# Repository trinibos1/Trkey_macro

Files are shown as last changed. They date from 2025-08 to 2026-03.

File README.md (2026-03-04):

# Trkey Macropad
## Overview

This is a **compact 3×3 macropad** built with **Raspberry Pi Pico / RP2040**, running **CircuitPython/Arduino**. It connects via **USB** using the **Adafruit HID library**, allowing you to assign keyboard shortcuts, media keys, and macros. An **OLED display** shows layer and status information for easy feedback. 
* **OLED Display:** [Amazon Link](https://a.co/d/afDOQYH)
* **PCB Design:** [OSH Park Project](https://oshpark.com/shared_projects/1jOtq57X)
* **Web Key Mapper:** [trinibos1/Trkey\_mapper](https://trinibos1.github.io/TRkey_mapper/)

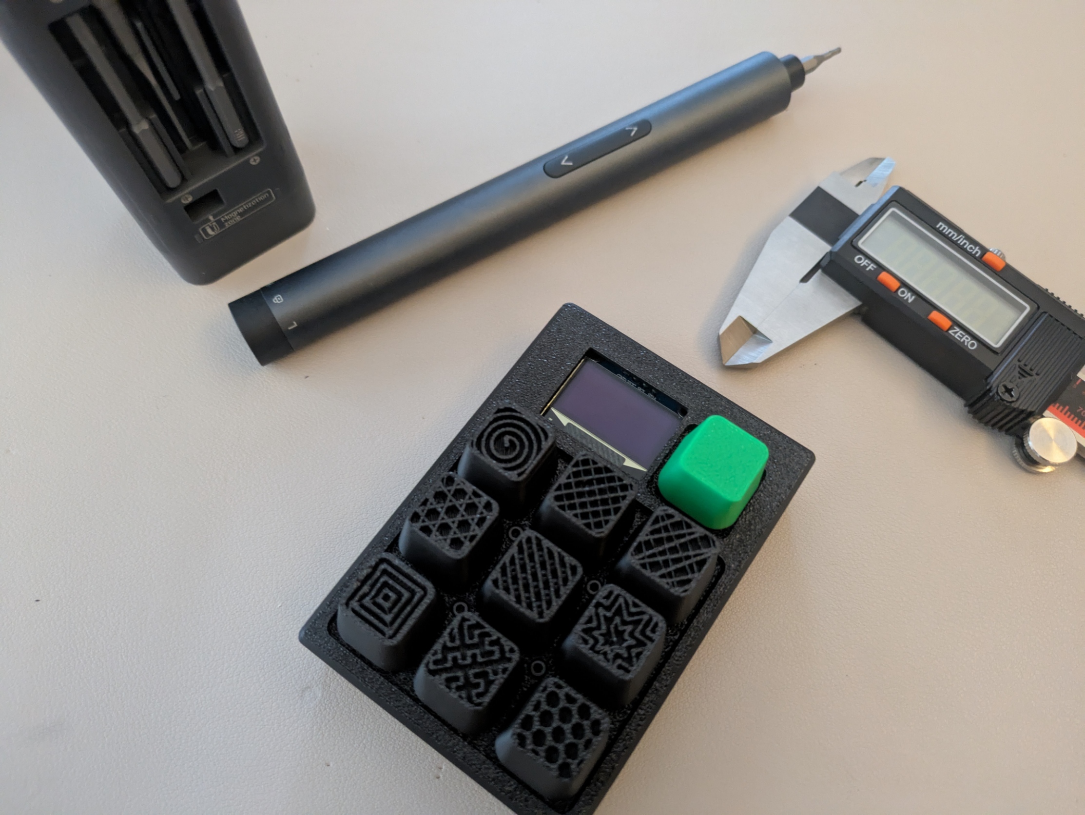
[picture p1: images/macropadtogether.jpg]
PCB Image

---
## Update

* UF2 file is old but code is up to date
* wireless trkey macropad has started development
---
## Changelog / Update Log

- **2026-02-14**
  - Added startup boot animation to main Arduino sketch (`arduino/Trkey_macro.ino`) with 3x3 box reveal, `TRKEY` splash, and version text.
  - Added dedicated WebSerial + USB connection guide (`WEBSERIAL_CONNECTION.md`).
  - Improved Arduino firmware compatibility and robustness:
    - HID report ID fixes for keyboard/media reports.
    - Numeric key token support (`"1".."0"`) plus legacy aliases (`"ONE".."ZERO"`).
    - RAM-backed `layers.json` handling when LittleFS is unavailable.
    - Safer JSON fallback behavior and macro ID parsing improvements.
    - USB descriptor naming updates for Trkey product/manufacturer.

## Features

* 3×3 Cherry MX Brown Hyperglide 45g tactile mechanical key matrix
* USB HID support (no Bluetooth)
* OLED display for layer/status feedback
* Tap/Hold functionality for advanced key actions
* Multiple layers for extended shortcut options
* Fast and responsive keypresses
* Simple wiring: switches connect directly to GND
* **All-in-one UF2:** CircuitPython, libraries, and firmware code included

---

## Hardware

| Component | Details |
| --- | --- |
| Microcontroller | Raspberry Pi Pico / RP2040 |
| Switches | 9x Cherry MX Brown Hyperglide 45g tactile |
| Display | OLED I2C 128x32 ([link](https://a.co/d/afDOQYH)) |
| PCB | Custom 3×3 macropad ([link](https://oshpark.com/shared_projects/1jOtq57X)) |
| Power | USB only |

PCB 
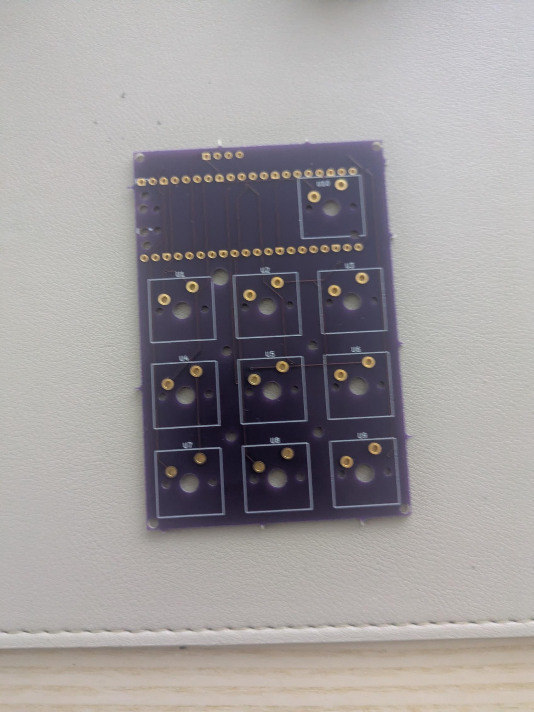
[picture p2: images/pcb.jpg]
PCB Image


---

## Firmware

**UF2 Firmware:**


* `macropad.uf2` — stable, all-in-one with CircuitPython, libraries, and code
* `dev_firmware.uf2` — development version for testing new features

**Key Features:** Tap/Hold, Layers, Media keys

### Arduino IDE firmware (C/C++)

If you want to move from CircuitPython to Arduino IDE, use `arduino/Trkey_macro.ino`.

Startup animation is now included in the main sketch (`arduino/Trkey_macro.ino`).

For beta experiments, you can still use `arduino/Trkey_macro_Beta.ino` (also provided as `arduino/Trkey_macro Beta.ino`).

This sketch keeps the same behavior as `code.py`:
- 3x3 key scanning with debounce + key repeat
- Layer functions: `MO(x)`, `TO(x)`, `TT(x)`, `DF(x)`
- Media keys + keyboard combos + text macros (`MACRO_n`)
- Text macro typing fallback is ASCII-only (`A-Z`, `a-z`, `0-9`, space, newline)
- OLED layer/key UI (with highlighted key and boxed grid)
- Serial command protocol for `LIST`, `GET`, `PUT`, `DEL`, `RELOAD`
- Macros can be defined on any layer; duplicate IDs use the last parsed definition

Required Arduino libraries:
- Adafruit SSD1306
- Adafruit GFX Library
- TinyUSB from the RP2040 board core (`Adafruit_TinyUSB_Arduino`)
- ArduinoJson
- LittleFS (included with RP2040 core)

Recommended board core: **Raspberry Pi Pico/RP2040** (Earle Philhower core).

RP2040 TinyUSB note (important):
- Do **not** call `tusb_init()` in your sketch (the RP2040 Arduino core already initializes TinyUSB).
- Prefer the TinyUSB bundled with the RP2040 core (`Adafruit_TinyUSB_Arduino`).
- If you installed `Documents/Arduino/libraries/Adafruit_TinyUSB_Library`, remove it to avoid library conflicts.

Documentation:
- `WEBSERIAL_CONNECTION.md` — USB CDC/WebSerial command flow, upload handshake, persistence behavior, and troubleshooting.
- `layers.json` in repo root — example keymap/profile format used by firmware and mapper.

---

## Usage

1. **Flash the UF2** (`macropad.uf2` or `dev_firmware.uf2`) onto your Pico — everything is included, no additional setup needed.
2. **Plug in the macropad** — ready to use.
3. **Use your macropad**:

   * Tap switches for primary actions
   * Hold switches for secondary actions or layer switching
   * OLED displays the current layer and status

---

## Companion App (Beta)

This beta feature is implemented in **Arduino firmware** (`arduino/Trkey_macro.ino`) and an optional PC CLI app (`pc_companion/trkey_music_companion.py`).

- The macropad still works fully without the companion app.
- Companion mode adds now-playing OLED metadata and app events.
- You can switch to music layer by name with: `MODE music`.

Quick start:
1. Flash Arduino beta firmware (`arduino/Trkey_macro_Beta.ino`).
1. Flash Arduino firmware (`arduino/Trkey_macro.ino`).
2. Run companion app: `python pc_companion/trkey_music_companion.py --port <PORT>`.
3. In app CLI, type:
   - `music` to load the music layer by name.
   - `np Song|Artist|45|180|Spotify` to update metadata.

Supported companion key tokens (in `layers.json`):
- `APP_PLAY_PAUSE`
- `APP_NEXT`
- `APP_PREV`
- `APP_MUTE`
- `APP_VOL_UP`
- `APP_VOL_DOWN`
- `APP_SEEK_FWD_10`
- `APP_SEEK_BACK_10`

`APP_*` keys emit `APP_EVENT <token>` on serial and media actions also fallback to HID media controls.

## Web-Based Key Mapper

Customize your macropad's key bindings using the **web-based key mapper**:

* Full key remapping: Assign single keys or complex shortcuts to any of the 9 keys
* Multi-layer support: Configure multiple layers for extended functionality
* Macro support: Create macros for complex sequences
* Web Serial API: Communicate directly with your macropad via the browser

**Access the key mapper here:** [trinibos1/micropad\_web](https://github.com/trinibos1/micropad_web)

---

## Contributions

Contributions are welcome to **improve the key library**, including:

* Adding new key mappings or shortcuts
* Optimizing tap/hold behavior
* Enhancing multi-layer support
* Improving key response and stability

Submit issues or pull requests to collaborate.
---
## 🙌 Thanks

Huge thanks to **[Adafruit](https://www.adafruit.com/)** for their amazing hardware and the **CircuitPython** + library ecosystem.  
Without their work, projects like this macropad wouldn’t be possible. 💜
---

## License

MIT License – see [LICENSE](LICENSE) for details.
---
## contact
Email: Trinibos1@proton.me

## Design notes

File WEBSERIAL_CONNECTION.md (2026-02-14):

# Trkey WebSerial + USB Connection Guide

This document explains how Trkey firmware communicates with the web app over USB Serial, how uploads are acknowledged, and how USB naming works.

## 1) USB Modes Used by Firmware

The firmware exposes:

- **USB HID** (keyboard + consumer/media reports)
- **USB CDC Serial** (line-based command channel used by Trkey Mapper)

At startup, firmware sets USB descriptor strings to:

- Manufacturer: `Trkey`
- Product: `Trkey`
- Serial: `TRKEY`

> Note: some OS UIs still show a generic serial path (`COMx`, `/dev/ttyACM*`, `/dev/cu.usbmodem*`) even when product/manufacturer strings are set correctly.

## 2) WebSerial Command Protocol

All commands are newline-terminated text lines.

### `LIST`

**Send:**

`LIST`

**Reply:**

- `Files:`
- one filename per line
- `<END>`

If LittleFS is unavailable, firmware still reports:
# Trkey WebSerial Connection Guide

This document explains how the Trkey firmware connects to the web app (Trkey Mapper) over USB Serial and which command flow is expected.

## Overview

The Arduino firmware exposes a simple line-based protocol on USB CDC Serial (`Serial`) so the browser app can:

- list files
- read `layers.json`
- upload `layers.json`
- reload layers in runtime

The command handler is in `arduino/Trkey_macro.ino` (`handleCommand()` + `processSerial()`).

## Serial Protocol

All commands are newline-terminated text lines.

### 1) LIST

**App sends**

`LIST`

**Firmware replies**

- `Files:`
- one file per line
- `<END>`

If LittleFS is unavailable, firmware still returns:

- `layers.json`
- `<END>`

### `GET <file>`

**Send:**

`GET layers.json`

**Reply:**

- raw file bytes
- `<EOF>` marker (`<EOF>\n`)

When filesystem is unavailable:

- returns RAM-backed `layers.json` (if uploaded in this runtime), otherwise
- returns built-in default JSON.

### `PUT <file>`

**Send:**

`PUT layers.json`

**Immediate reply:**

`READY`

Then app sends file bytes and terminates stream with:

`<EOF>`

**Completion replies:**

- `FILE RECEIVED`
- for `layers.json`: `LAYERS RELOADED`

### `RELOAD`

**Send:**

`RELOAD`

**Reply:**

`LAYERS RELOADED`

### `DEL <file>`

Deletes a file from LittleFS. If FS is unavailable, returns `ERROR`.

## 3) Expected Upload Handshake

Recommended app flow:

1. Send `PUT layers.json`
2. Wait for `READY`
### 2) GET <file>

**App sends**

`GET layers.json`

**Firmware replies**

- raw file bytes
- `<EOF>` marker (sent as `<EOF>\n`)

If filesystem is unavailable:

- returns RAM-backed `layers.json` if one was uploaded in this session
- otherwise returns firmware default JSON

### 3) PUT <file>

**App sends**

`PUT layers.json`

**Firmware replies first**

`READY`

Then app streams file contents and terminates with:

`<EOF>`

**Firmware replies after EOF**

- `FILE RECEIVED`
- for `layers.json`, it then reloads and sends `LAYERS RELOADED`

### 4) RELOAD

**App sends**

`RELOAD`

**Firmware replies**

`LAYERS RELOADED`

## Why you may see "READY" + "FILE RECEIVED"

This is expected behavior for `PUT`:

1. firmware acknowledges upload start with `READY`
2. app sends bytes + `<EOF>`
3. firmware confirms write with `FILE RECEIVED`
4. firmware reloads config and emits `LAYERS RELOADED`

If the web app is currently waiting only for `FILE RECEIVED`, a delayed `READY` line can appear as an "unexpected line" in logs even though the flow is healthy.

## Persistence Behavior

- If LittleFS is available: uploaded `layers.json` is written to flash.
- If LittleFS is unavailable: uploaded `layers.json` is stored in RAM (`ramLayersJson`) for this runtime session.

That RAM-backed path allows `GET layers.json` and `RELOAD` to keep using the uploaded config even without filesystem access.

## Minimal App Upload Sequence (recommended)

1. Send `PUT layers.json`
2. Wait until `READY`
3. Send JSON bytes
4. Send `<EOF>`
5. Wait for `FILE RECEIVED`
6. Optionally wait for `LAYERS RELOADED`

If `READY` appears as an "unexpected line" while waiting for `FILE RECEIVED`, that usually means your app state machine consumed lines out of phase. The firmware sequence above is expected.

## 4) Persistence Behavior

- **LittleFS available:** upload is persisted to flash.
- **LittleFS unavailable:** upload is stored in RAM for this runtime session.

RAM-backed config supports `GET layers.json` + `RELOAD`, but it is not power-cycle persistent.

## 5) JSON Compatibility Notes

Firmware accepts both:

- top-level array of layers, or
- object with a `layers` array (recommended)

It supports numeric key tokens (`"1".."0"`) and word aliases (`"ONE".."ZERO"`).

## 6) Troubleshooting

- `UNKNOWN COMMAND`: command is malformed or not newline-terminated.
- `FILE RECEIVED` never arrives: app did not send `<EOF>` marker correctly.
- Config reloads but seems unchanged: verify uploaded JSON parses and layer keys are valid tokens.
- Device name not updated: reflash and unplug/replug to force USB re-enumeration.
## Troubleshooting

- If the device returns `UNKNOWN COMMAND`, verify each command is newline-terminated.
- If upload appears successful but config is unchanged, ensure app waits for `READY` before sending file bytes.
- If filesystem is unavailable, behavior is session-persistent only (RAM), not power-cycle persistent.

### 5) NP_SET <json>

Send now-playing metadata from the optional PC companion app.

**Send**

`NP_SET {"title":"Track","artist":"Artist","position":12,"duration":180,"source":"Spotify"}`

**Reply**

`NP_OK`

Notes:
- Metadata is in RAM only.
- OLED switches to a now-playing overlay and auto-hides after inactivity.

### 6) NP_CLEAR

**Send**

`NP_CLEAR`

**Reply**

`NP_CLEARED`

### 7) NP_GET

**Send**

`NP_GET`

**Reply**

single-line JSON of current now-playing state.

### Companion action events

When a key is mapped to an `APP_*` token in `layers.json`, firmware emits:

`APP_EVENT <token>`

Example:

`APP_EVENT APP_PLAY_PAUSE`

These actions are optional companion features. The macropad does not require a companion app for normal HID operation.

### 8) MODE <name-or-index>

Switch active layer by index or name.

**Examples**
- `MODE 3`
- `MODE music`

Name matching is case-insensitive and supports partial match.

**Reply**
- `MODE LOADED`
- or `ERROR: MODE NOT FOUND`

### 9) MODE LIST

List available layer names for mode switching.

**Send**

`MODE LIST`

**Reply**
- `Modes:`
- `<index>: <layer-name>` per line
- `<END>`

### PC app

A basic optional PC companion CLI app is included at:

`pc_companion/trkey_music_companion.py`

It supports `music` shortcut (`MODE music`), metadata pushes (`NP_SET`), and prints `APP_EVENT` lines.

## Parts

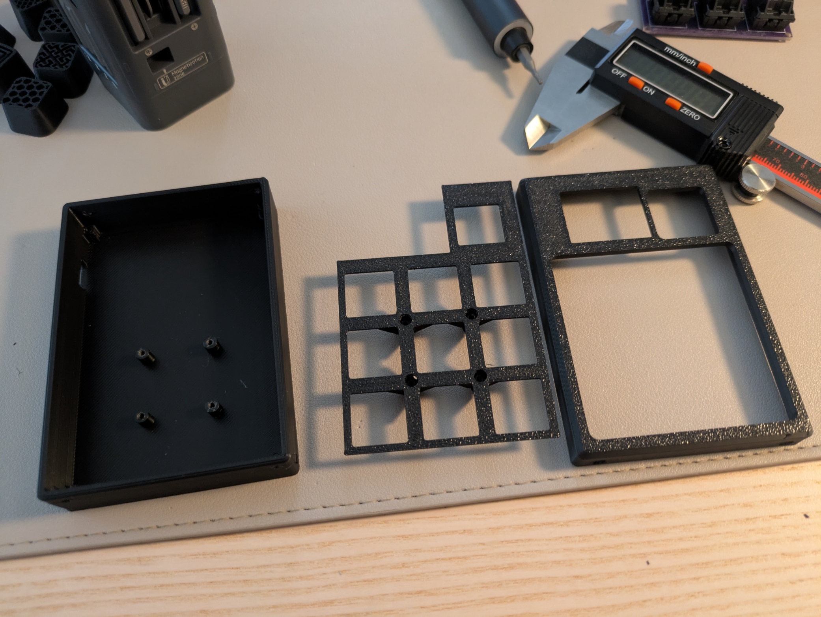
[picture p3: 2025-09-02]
images/macropad printed parts nly.jpg

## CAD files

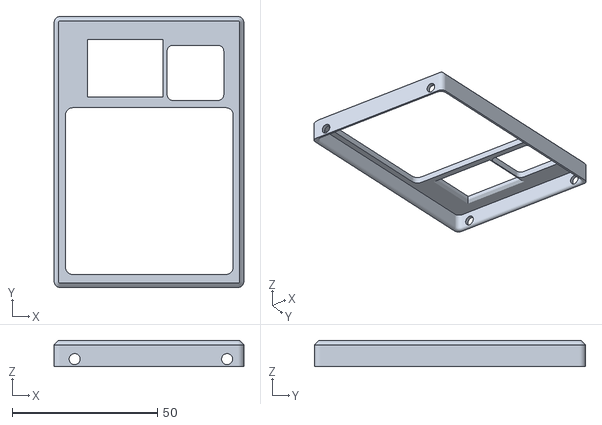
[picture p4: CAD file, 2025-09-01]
case/oldcase/macropad top.stl
65.3 x 93.3 x 9.00

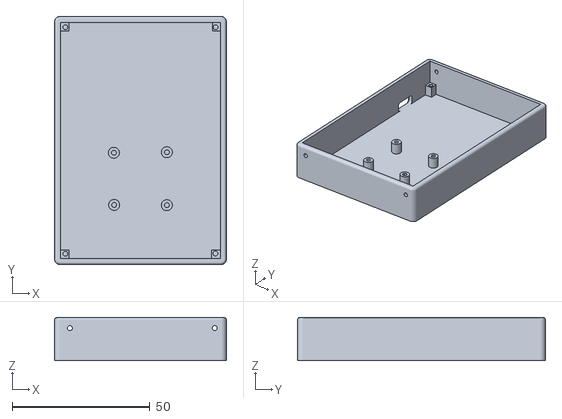
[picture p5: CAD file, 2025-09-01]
case/oldcase/macropad bottom .stl
62.3 x 89.9 x 15.7

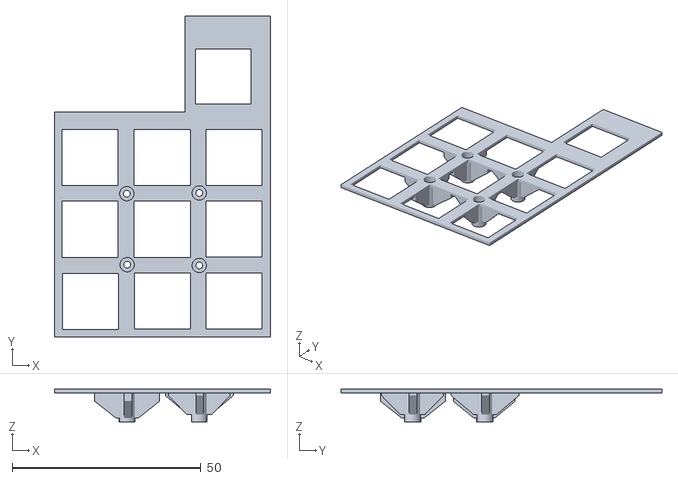
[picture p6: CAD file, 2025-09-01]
case/oldcase/macropad mid.stl
57.2 x 85.0 x 8.62

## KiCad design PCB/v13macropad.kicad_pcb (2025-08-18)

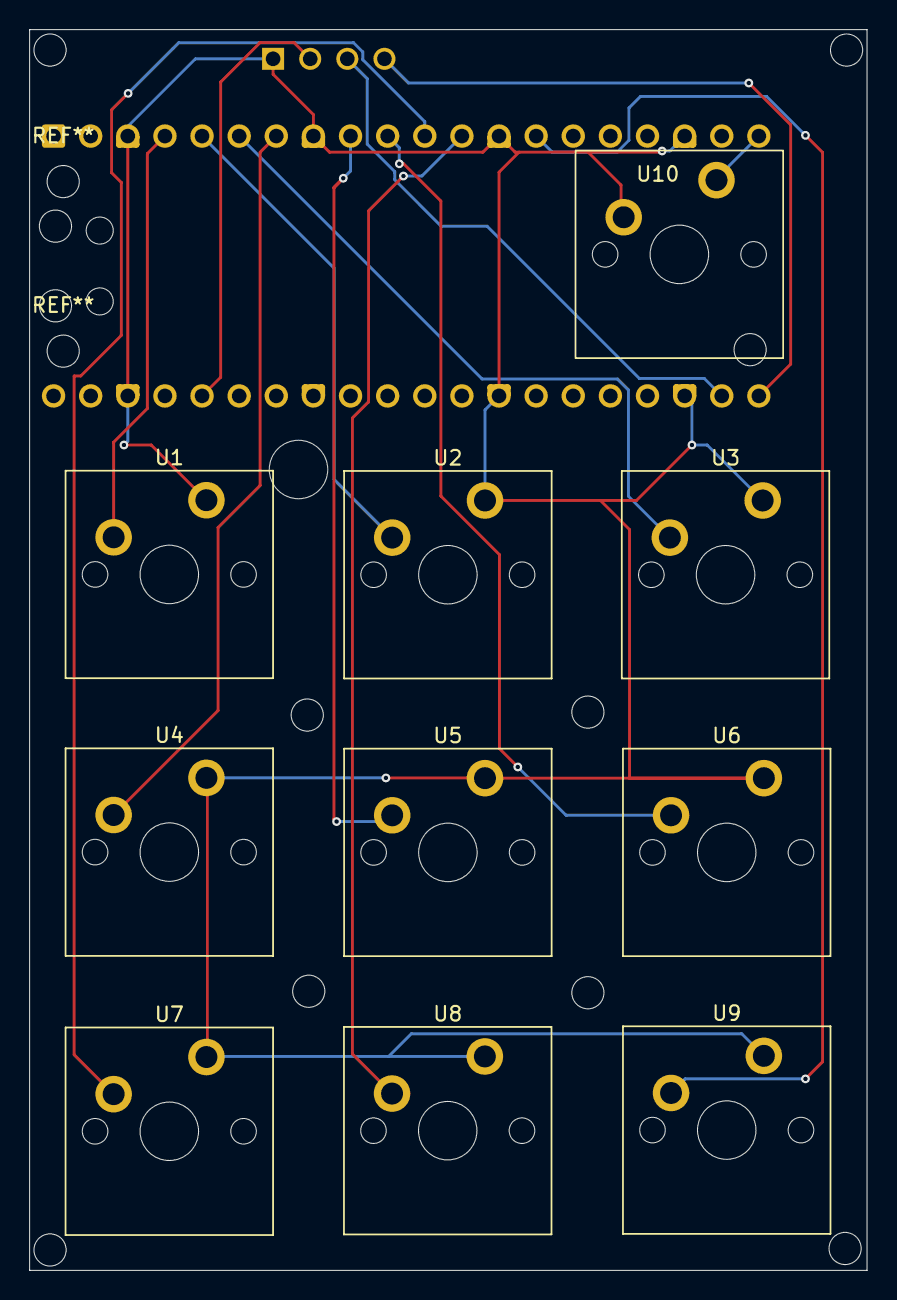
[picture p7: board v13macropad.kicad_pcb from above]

Board: 2 copper layers, 57.3 x 84.9 mm, 12 parts (1 on the bottom side), 11 nets.

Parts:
A1: RaspberryPi_Pico; RaspberryPi_Pico_Common
U1, U2, U3, U4, U5, U6, U7, U8, U9, U10: MX1A-11NN; SW_Cherry_MX_PCB_1.00u
U11: DM-OLED096-636; MODULE_DM-OLED096-636

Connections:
BAT+: A1.6 (GPIO4), A1.10 (GPIO7), A1.14 (GPIO10), A1.36 (3V3), A1.39 (VSYS), A1.40 (VBUS), U3.1, U6.1, U9.1, U11.2 (VCC_IN)
Earth: A1.3 (GND), A1.8 (GND), A1.13 (GND), A1.18 (GND), A1.23 (GND), A1.28 (GND), A1.38 (GND), U1.2, U2.2, U3.2, U4.2, U5.2, U6.2, U7.2, U8.2, U9.2, U10.1, U11.1 (GND)
unnamed: A1.4 (GPIO2), U1.1
unnamed: A1.5 (GPIO3), U2.1
unnamed: A1.7 (GPIO5), U4.1
unnamed: A1.9 (GPIO6), U5.1
unnamed: A1.11 (GPIO8), U7.1
unnamed: A1.12 (GPIO9), U8.1
unnamed: A1.20 (GPIO15), U10.2
unnamed: A1.21 (GPIO16), U11.4 (SDA)
unnamed: A1.22 (GPIO17), U11.3 (SCL)

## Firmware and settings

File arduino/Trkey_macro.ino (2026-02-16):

#include <Arduino.h>
#include <Wire.h>
#include <Adafruit_GFX.h>
#include <Adafruit_SSD1306.h>
#include <Adafruit_TinyUSB.h>
#include <ArduinoJson.h>
#include <EEPROM.h>
#include <map>
#include <vector>

// ===== Firmware Version =====
#define FW_VERSION "v2.5.4"

// ===== Display =====
static constexpr uint8_t OLED_ADDR = 0x3C;
static constexpr int SCREEN_WIDTH = 128;
static constexpr int SCREEN_HEIGHT = 64;
Adafruit_SSD1306 display(SCREEN_WIDTH, SCREEN_HEIGHT, &Wire, -1);

// ===== Timing =====
static constexpr uint32_t DEBOUNCE_MS = 100;
static constexpr uint32_t PRESS_DISPLAY_MS = 300;
static constexpr uint32_t REPEAT_DELAY_MS = 400;
static constexpr uint32_t REPEAT_RATE_MS = 50;

// ===== Pins =====
const uint8_t keyPins[9] = {2, 3, 4, 5, 6, 7, 8, 9, 10};
const uint8_t layerSwitchPin = 15;

// ===== TinyUSB HID (WORKING from your code) =====
Adafruit_USBD_HID usb_hid;
uint8_t const hidReportDescriptor[] = {
  TUD_HID_REPORT_DESC_KEYBOARD(HID_REPORT_ID(1)),
  TUD_HID_REPORT_DESC_CONSUMER(HID_REPORT_ID(2))
};
static constexpr uint8_t KEYBOARD_REPORT_ID = 1;
static constexpr uint8_t CONSUMER_REPORT_ID = 2;

// ===== EEPROM Config Storage =====
#define EEPROM_SIZE 16384
#define CONFIG_ADDR 0
#define CONFIG_MAGIC 0xDEADBEEF

// ===== Config models =====
struct Layer {
  String name;
  String labels[9];
  String keys[9];
};

std::vector<Layer> layers;
std::map<int, String> macros;
int currentLayer = 0;
int defaultLayer = 0;

// ===== Key state =====
bool repeatActive[9] = {false};
uint32_t repeatStart[9] = {0};
uint32_t repeatLast[9] = {0};
uint32_t keyDebounceStart[9] = {0};
bool moActive[9] = {false};
int moPrevLayer[9] = {0};
int moTargetForKey[9] = {0};
int pressedIndex = -1;
uint32_t lastPressMs = 0;
bool lastLayerSwitchState = true;

// ===== CDC transfer state =====
bool receivingFile = false;
String putFilename;
String serialLineBuffer;
uint8_t eofWindow[5] = {0};
uint8_t eofWindowLen = 0;
bool discardingUpload = false;
String putBuffer;

// ===== HID maps =====
std::map<String, uint8_t> keyMap;
std::map<String, uint16_t> consumerMap;

String normalizePathArg(const String& rawArg) {
  String f = rawArg;
  f.trim();
  while (f.startsWith("/")) f.remove(0, 1);
  return f.length() ? String("/") + f : String("/");
}

const char* defaultLayersJson() {
  return R"JSON({"grid_size":3,"layers":[{"name":"Layer 0","labels":["A","B","C","D","E","F","G","H","I"],"keys":["A","B","C","D","E","F","G","H","I"]}]})JSON";
}

void sendLine(const char* msg) {
  Serial.print(msg);
  Serial.print("\n");
  Serial.flush();
}

void sendEOFMarker() {
  Serial.write(reinterpret_cast<const uint8_t*>("<EOF>\n"), 6);
  Serial.flush();
}

void initKeyMaps() {
  keyMap["A"] = HID_KEY_A; keyMap["B"] = HID_KEY_B; keyMap["C"] = HID_KEY_C;
  keyMap["D"] = HID_KEY_D; keyMap["E"] = HID_KEY_E; keyMap["F"] = HID_KEY_F;
  keyMap["G"] = HID_KEY_G; keyMap["H"] = HID_KEY_H; keyMap["I"] = HID_KEY_I;
  keyMap["J"] = HID_KEY_J; keyMap["K"] = HID_KEY_K; keyMap["L"] = HID_KEY_L;
  keyMap["M"] = HID_KEY_M; keyMap["N"] = HID_KEY_N; keyMap["O"] = HID_KEY_O;
  keyMap["P"] = HID_KEY_P; keyMap["Q"] = HID_KEY_Q; keyMap["R"] = HID_KEY_R;
  keyMap["S"] = HID_KEY_S; keyMap["T"] = HID_KEY_T; keyMap["U"] = HID_KEY_U;
  keyMap["V"] = HID_KEY_V; keyMap["W"] = HID_KEY_W; keyMap["X"] = HID_KEY_X;
  keyMap["Y"] = HID_KEY_Y; keyMap["Z"] = HID_KEY_Z;
  keyMap["1"] = HID_KEY_1; keyMap["2"] = HID_KEY_2; keyMap["3"] = HID_KEY_3;
  keyMap["4"] = HID_KEY_4; keyMap["5"] = HID_KEY_5; keyMap["6"] = HID_KEY_6;
  keyMap["7"] = HID_KEY_7; keyMap["8"] = HID_KEY_8; keyMap["9"] = HID_KEY_9;
  keyMap["0"] = HID_KEY_0;
  keyMap["ENTER"] = HID_KEY_ENTER;
  keyMap["ESCAPE"] = HID_KEY_ESCAPE;
  keyMap["TAB"] = HID_KEY_TAB;
  keyMap["SPACE"] = HID_KEY_SPACE;
  keyMap["BACKSPACE"] = HID_KEY_BACKSPACE;
  keyMap["CONTROL"] = HID_KEY_CONTROL_LEFT;
  keyMap["CTRL"] = HID_KEY_CONTROL_LEFT;
  keyMap["SHIFT"] = HID_KEY_SHIFT_LEFT;
  keyMap["ALT"] = HID_KEY_ALT_LEFT;
  keyMap["GUI"] = HID_KEY_GUI_LEFT;

  consumerMap["PLAY_PAUSE"] = HID_USAGE_CONSUMER_PLAY_PAUSE;
  consumerMap["MUTE"] = HID_USAGE_CONSUMER_MUTE;
  consumerMap["VOLUME_INCREMENT"] = HID_USAGE_CONSUMER_VOLUME_INCREMENT;
  consumerMap["VOLUME_DECREMENT"] = HID_USAGE_CONSUMER_VOLUME_DECREMENT;
#if defined(HID_USAGE_CONSUMER_SCAN_NEXT)
  consumerMap["SCAN_NEXT_TRACK"] = HID_USAGE_CONSUMER_SCAN_NEXT;
#elif defined(HID_USAGE_CONSUMER_SCAN_NEXT_TRACK)
  consumerMap["SCAN_NEXT_TRACK"] = HID_USAGE_CONSUMER_SCAN_NEXT_TRACK;
#endif
#if defined(HID_USAGE_CONSUMER_SCAN_PREVIOUS)
  consumerMap["SCAN_PREVIOUS_TRACK"] = HID_USAGE_CONSUMER_SCAN_PREVIOUS;
#elif defined(HID_USAGE_CONSUMER_SCAN_PREVIOUS_TRACK)
  consumerMap["SCAN_PREVIOUS_TRACK"] = HID_USAGE_CONSUMER_SCAN_PREVIOUS_TRACK;
#endif
  consumerMap["STOP"] = HID_USAGE_CONSUMER_STOP;
}

bool isNoop(const String& s) {
  return s.length() == 0 || s == "NO_OP";
}

void drawUI(int layerIdx, int activeIdx = -1) {
  if (layers.empty()) return;
  display.clearDisplay();
  display.setTextColor(SSD1306_WHITE);
  display.setTextSize(1);
  display.setCursor(0, 0);
  display.print("Layer: ");
  display.print(layers[layerIdx].name);
  display.print(" ");
  display.print(layerIdx + 1);
  display.print("/");
  display.print(layers.size());

  const int startX = 2, startY = 14, cellW = 41, cellH = 16;
  for (int i = 0; i < 9; i++) {
    int x = startX + (i % 3) * cellW;
    int y = startY + (i / 3) * cellH;
    display.drawRect(x, y, 39, 14, SSD1306_WHITE);
    if (i == activeIdx) {
      display.fillRect(x + 1, y + 1, 37, 12, SSD1306_WHITE);
      display.setTextColor(SSD1306_BLACK);
    } else {
      display.setTextColor(SSD1306_WHITE);
    }
    String txt = layers[layerIdx].labels[i];
    if (txt.length() > 5) txt = txt.substring(0, 5);
    display.setCursor(x + 2, y + 4);
    display.print(txt);
  }
  display.display();
}

// WORKING HID from your code
void sendKeyboardReport(uint8_t modifiers, uint8_t keys[6]) {
  usb_hid.keyboardReport(KEYBOARD_REPORT_ID, modifiers, keys);
}

void tapKey(uint8_t keycode) {
  uint8_t keys[6] = {keycode, 0, 0, 0, 0, 0};
  sendKeyboardReport(0, keys);
  delay(50);
  uint8_t empty[6] = {0, 0, 0, 0, 0, 0};
  sendKeyboardReport(0, empty);
}

bool parseLayerFn(const String& in, String& fn, int& target) {
  int p1 = in.indexOf('(');
  int p2 = in.indexOf(')');
  if (p1 < 0 || p2 < 0 || p2 <= p1 + 1) return false;
  fn = in.substring(0, p1);
  fn.toUpperCase();
  target = in.substring(p1 + 1, p2).toInt();
  return fn == "MO" || fn == "TO" || fn == "TT" || fn == "DF";
}

void typeText(const String& text) {
  for (size_t i = 0; i < text.length(); i++) {
    char c = text[i];
    if (c >= 'a' && c <= 'z') tapKey(HID_KEY_A + (c - 'a'));
    else if (c >= 'A' && c <= 'Z') {
      uint8_t keys[6] = {static_cast<uint8_t>(HID_KEY_A + (c - 'A')), 0, 0, 0, 0, 0};
      sendKeyboardReport(KEYBOARD_MODIFIER_LEFTSHIFT, keys);
      delay(50);
      uint8_t empty[6] = {0, 0, 0, 0, 0, 0};
      sendKeyboardReport(0, empty);
    }
    else if (c == ' ') tapKey(HID_KEY_SPACE);
    else if (c == '\n') tapKey(HID_KEY_ENTER);
    else if (c >= '0' && c <= '9') tapKey(HID_KEY_0 + (c - '0'));
    delay(5);
  }
}

void sendCombo(const std::vector<uint8_t>& combo) {
  uint8_t modifiers = 0;
  uint8_t keys[6] = {0, 0, 0, 0, 0, 0};
  int keySlot = 0;
  for (uint8_t kc : combo) {
    switch (kc) {
      case HID_KEY_CONTROL_LEFT: modifiers |= KEYBOARD_MODIFIER_LEFTCTRL; break;
      case HID_KEY_SHIFT_LEFT: modifiers |= KEYBOARD_MODIFIER_LEFTSHIFT; break;
      case HID_KEY_ALT_LEFT: modifiers |= KEYBOARD_MODIFIER_LEFTALT; break;
      case HID_KEY_GUI_LEFT: modifiers |= KEYBOARD_MODIFIER_LEFTGUI; break;
      default:
        if (keySlot < 6) keys[keySlot++] = kc;
        break;
    }
  }
  sendKeyboardReport(modifiers, keys);
  delay(50);
  uint8_t empty[6] = {0, 0, 0, 0, 0, 0};
  sendKeyboardReport(0, empty);
}

void sendMacroSequence(const String& seq) {
  if (seq.indexOf('+') >= 0) {
    std::vector<uint8_t> combo;
    int start = 0;
    while (start < seq.length()) {
      int plus = seq.indexOf('+', start);
      String part = plus < 0 ? seq.substring(start) : seq.substring(start, plus);
      part.trim();
      part.toUpperCase();
      if (keyMap.count(part)) combo.push_back(keyMap[part]);
      start = plus < 0 ? seq.length() : plus + 1;
    }
    if (!combo.empty()) sendCombo(combo);
  } else {
    typeText(seq);
  }
}

void handleLayerFn(const String& fn, int target, int keyIndex, bool onPress) {
  target = constrain(target, 0, static_cast<int>(layers.size()) - 1);
  if (fn == "MO") {
    if (onPress) {
      moPrevLayer[keyIndex] = currentLayer;
      moActive[keyIndex] = true;
      moTargetForKey[keyIndex] = target;
      currentLayer = target;
      drawUI(currentLayer);
    } else if (moActive[keyIndex]) {
      currentLayer = moPrevLayer[keyIndex];
      moActive[keyIndex] = false;
      drawUI(currentLayer);
    }
    return;
  }
  if (!onPress) return;
  if (fn == "TO") currentLayer = target;
  else if (fn == "TT") currentLayer = currentLayer == target ? defaultLayer : target;
  else if (fn == "DF") { defaultLayer = target; currentLayer = target; }
  drawUI(currentLayer);
}

void sendKeyEntry(const String& rawEntry, int keyIndex, bool onPress) {
  String entry = rawEntry;
  entry.trim();
  if (isNoop(entry)) return;

  String fn;
  int target = 0;
  if (parseLayerFn(entry, fn, target)) {
    handleLayerFn(fn, target, keyIndex, onPress);
    return;
  }

  String up = entry;
  up.toUpperCase();

  if (consumerMap.count(up)) {
    if (onPress) usb_hid.sendReport16(CONSUMER_REPORT_ID, consumerMap[up]);
    delay(5);
    usb_hid.sendReport16(CONSUMER_REPORT_ID, 0);
    return;
  }

  if (up.startsWith("MACRO_")) {
    if (onPress) {
      int id = up.substring(6).toInt();
      if (macros.count(id)) sendMacroSequence(macros[id]);
    }
    return;
  }

  if (up.indexOf('_') >= 0) {
    std::vector<uint8_t> combo;
    int start = 0;
    while (start < up.length()) {
      int sep = up.indexOf('_', start);
      String tok = sep < 0 ? up.substring(start) : up.substring(start, sep);
      tok.trim();
      if (keyMap.count(tok)) combo.push_back(keyMap[tok]);
      else {
        combo.clear();
        break;
      }
      start = sep < 0 ? up.length() : sep + 1;
    }
    if (onPress && !combo.empty()) sendCombo(combo);
    return;
  }

  if (onPress && keyMap.count(up)) tapKey(keyMap[up]);
}

void loadHardcodedSafeLayer() {
  layers.clear();
  Layer safe;
  safe.name = "Layer 0";
  const char* defaults[9] = {"A", "B", "C", "D", "E", "F", "G", "H", "I"};
  for (int i = 0; i < 9; i++) {
    safe.labels[i] = defaults[i];
    safe.keys[i] = defaults[i];
  }
  layers.push_back(safe);
  macros.clear();
  currentLayer = 0;
  defaultLayer = 0;
}

int parseMacroId(JsonObject mo) {
  if (!mo["id"].isNull()) {
    int id = mo["id"].as<int>();
    if (id >= 0) return id;
  }
  const char* macroName = mo["name"] | "";
  if (macroName && macroName[0]) {
    String name = String(macroName);
    name.trim();
    name.toUpperCase();
    if (name.startsWith("MACRO ")) {
      int parsed = name.substring(6).toInt();
      if (parsed > 0) return parsed;
    }
  }
  return -1;
}

void parseLayerArray(JsonArray arr) {
  layers.clear();
  for (JsonVariant v : arr) {
    if (!v.is<JsonObject>()) continue;
    JsonObject obj = v.as<JsonObject>();
    Layer l;
    l.name = obj["name"] | "Layer";
    JsonArray labels = obj["labels"].as<JsonArray>();
    JsonArray keys = obj["keys"].as<JsonArray>();
    for (int i = 0; i < 9; i++) {
      l.labels[i] = labels.isNull() || i >= labels.size() ? "" : String((const char*)labels[i]);
      l.keys[i] = keys.isNull() || i >= keys.size() ? "" : String((const char*)keys[i]);
    }
    if (layers.empty()) {
      JsonArray mArr = obj["macros"].as<JsonArray>();
      if (!mArr.isNull()) {
        for (JsonVariant m : mArr) {
          if (!m.is<JsonObject>()) continue;
          JsonObject mo = m.as<JsonObject>();
          int id = parseMacroId(mo);
          if (id < 0) continue;
          macros[id] = String((const char*)(mo["sequence"] | ""));
        }
      }
    }
    layers.push_back(l);
  }
}

bool loadLayersFromJsonDocument(DynamicJsonDocument& doc) {
  macros.clear();
  if (doc.is<JsonArray>()) {
    parseLayerArray(doc.as<JsonArray>());
  } else if (doc.is<JsonObject>() && doc["layers"].is<JsonArray>()) {
    parseLayerArray(doc["layers"].as<JsonArray>());
  }
  if (layers.empty()) return false;
  currentLayer = constrain(currentLayer, 0, static_cast<int>(layers.size()) - 1);
  defaultLayer = constrain(defaultLayer, 0, static_cast<int>(layers.size()) - 1);
  return true;
}

bool loadBuiltinDefaultLayers() {
  DynamicJsonDocument doc(2048);
  auto err = deserializeJson(doc, defaultLayersJson());
  if (err) return false;
  return loadLayersFromJsonDocument(doc);
}

// ===== EEPROM Storage Functions =====

void saveConfigToEEPROM(const String& json) {
  EEPROM.begin(EEPROM_SIZE);
  
  int len = json.length();
  if (len > EEPROM_SIZE - 10) {
    Serial.println("ERROR: Config too large for EEPROM");
    return;
  }
  
  uint32_t ulen = (uint32_t)len;
  EEPROM.write(CONFIG_ADDR, (CONFIG_MAGIC >> 24) & 0xFF);
  EEPROM.write(CONFIG_ADDR + 1, (CONFIG_MAGIC >> 16) & 0xFF);
  EEPROM.write(CONFIG_ADDR + 2, (CONFIG_MAGIC >> 8) & 0xFF);
  EEPROM.write(CONFIG_ADDR + 3, CONFIG_MAGIC & 0xFF);
  
  EEPROM.write(CONFIG_ADDR + 4, (ulen >> 24) & 0xFF);
  EEPROM.write(CONFIG_ADDR + 5, (ulen >> 16) & 0xFF);
  EEPROM.write(CONFIG_ADDR + 6, (ulen >> 8) & 0xFF);
  EEPROM.write(CONFIG_ADDR + 7, ulen & 0xFF);
  
  for (uint32_t i = 0; i < ulen; i++) {
    EEPROM.write(CONFIG_ADDR + 8 + i, (uint8_t)json[i]);
  }
  
  EEPROM.write(CONFIG_ADDR + 8 + ulen, 0);
  
  EEPROM.commit();
  Serial.print("Config saved: ");
  Serial.print(len);
  Serial.println(" bytes");
}

String loadConfigFromEEPROM() {
  EEPROM.begin(EEPROM_SIZE);
  
  uint32_t magic = ((uint32_t)EEPROM.read(CONFIG_ADDR) << 24) |
                   ((uint32_t)EEPROM.read(CONFIG_ADDR + 1) << 16) |
                   ((uint32_t)EEPROM.read(CONFIG_ADDR + 2) << 8) |
                   (uint32_t)EEPROM.read(CONFIG_ADDR + 3);
  
  if (magic != CONFIG_MAGIC) {
    return "";
  }
  
  uint32_t len = ((uint32_t)EEPROM.read(CONFIG_ADDR + 4) << 24) |
                 ((uint32_t)EEPROM.read(CONFIG_ADDR + 5) << 16) |
                 ((uint32_t)EEPROM.read(CONFIG_ADDR + 6) << 8) |
                 (uint32_t)EEPROM.read(CONFIG_ADDR + 7);
            
  if (len == 0 || len > EEPROM_SIZE - 10) {
    Serial.println("ERROR: Invalid config length");
    return "";
  }
  
  char* buffer = (char*)malloc(len + 1);
  if (!buffer) {
    Serial.println("ERROR: malloc failed");
    return "";
  }
  
  for (uint32_t i = 0; i < len; i++) {
    buffer[i] = (char)EEPROM.read(CONFIG_ADDR + 8 + i);
  }
  buffer[len] = '\0';
  
  String result = String(buffer);
  free(buffer);
  
  Serial.print("Config loaded: ");
  Serial.print(len);
  Serial.println(" bytes");
  
  return result;
}

void loadLayers() {
  macros.clear();
  
  String eepromConfig = loadConfigFromEEPROM();
  if (eepromConfig.length() > 0) {
    Serial.println("EEPROM config preview:");
    Serial.println(eepromConfig.substring(0, min(100, (int)eepromConfig.length())));
    
    DynamicJsonDocument doc(16384);
    auto err = deserializeJson(doc, eepromConfig);
    
    if (err) {
      Serial.print("JSON error: ");
      Serial.println(err.c_str());
    } else if (loadLayersFromJsonDocument(doc)) {
      Serial.println("Loaded from EEPROM OK");
      return;
    } else {
      Serial.println("loadLayersFromJsonDocument failed");
    }
  }
  
  Serial.println("Loading defaults");
  if (!loadBuiltinDefaultLayers()) {
    loadHardcodedSafeLayer();
  }
}

void handleCommand(const String& cmdRaw) {
  String cmd = cmdRaw;
  cmd.trim();
  if (discardingUpload) return;
  if (cmd == "<EOF>") return;

  if (cmd == "LIST") {
    sendLine("Files:");
    String eepromConfig = loadConfigFromEEPROM();
    if (eepromConfig.length() > 0) {
      sendLine("layers.json (EEPROM)");
    }
    sendLine("<END>");
    return;
  }

  if (cmd.startsWith("DEL ")) {
    EEPROM.begin(EEPROM_SIZE);
    EEPROM.write(CONFIG_ADDR, 0);
    EEPROM.commit();
    sendLine("DELETED");
    return;
  }

  if (cmd.startsWith("GET ")) {
    String fn = normalizePathArg(cmd.substring(4));
    if (fn == "/layers.json") {
      String eepromConfig = loadConfigFromEEPROM();
      if (eepromConfig.length() > 0) {
        Serial.print(eepromConfig);
      } else {
        Serial.print(defaultLayersJson());
      }
    }
    sendEOFMarker();
    return;
  }

  if (cmd.startsWith("PUT ")) {
    putFilename = normalizePathArg(cmd.substring(4));
    putBuffer = "";
    discardingUpload = false;

    if (putFilename != "/layers.json") {
      discardingUpload = true;
      Serial.println("ERROR: Only /layers.json supported");
    } else {
      Serial.println("Ready to receive layers.json");
    }
    
    receivingFile = true;
    eofWindowLen = 0;
    sendLine("READY");
    return;
  }

  if (cmd == "RELOAD") {
    loadLayers();
    drawUI(currentLayer);
    sendLine("LAYERS RELOADED");
    return;
  }

  sendLine("UNKNOWN COMMAND");
}

void processSerial() {
  while (Serial.available()) {
    uint8_t b = static_cast<uint8_t>(Serial.read());

    if (receivingFile) {
      eofWindow[eofWindowLen++] = b;
      if (eofWindowLen < 5) continue;

      if (eofWindow[0] == '<' && eofWindow[1] == 'E' && eofWindow[2] == 'O' && eofWindow[3] == 'F' && eofWindow[4] == '>') {
        receivingFile = false;
        eofWindowLen = 0;

        if (discardingUpload) {
          discardingUpload = false;
          putBuffer = "";
          sendLine("ERROR: Upload discarded");
          continue;
        }
        
        saveConfigToEEPROM(putBuffer);
        putBuffer = "";
        
        sendLine("FILE RECEIVED");
        
        if (putFilename == "/layers.json") {
          loadLayers();
          drawUI(currentLayer);
          sendLine("LAYERS RELOADED");
        }
        continue;
      }

      if (!discardingUpload) {
        putBuffer += static_cast<char>(eofWindow[0]);
      }
      
      for (uint8_t i = 1; i < 5; i++) eofWindow[i - 1] = eofWindow[i];
      eofWindowLen = 4;
      continue;
    }

    if (b == '\r') continue;
    if (b == '\n') {
      String cmd = serialLineBuffer;
      serialLineBuffer = "";
      cmd.trim();
      if (cmd.length()) handleCommand(cmd);
      continue;
    }
    serialLineBuffer += static_cast<char>(b);
  }
}

// ===== Boot Animation =====
void playBootAnimation() {
  const int startX = 2;
  const int startY = 14;
  const int cellW = 41;
  const int cellH = 16;

  // Step 1: animate 3x3 boxes appearing one by one.
  display.clearDisplay();
  display.setTextSize(1);
  display.setTextColor(SSD1306_WHITE);
  display.setCursor(22, 5);
  display.print("Booting...");
  display.display();

  for (int i = 0; i < 9; i++) {
    int x = startX + (i % 3) * cellW;
    int y = startY + (i / 3) * cellH;
    display.drawRect(x, y, 39, 14, SSD1306_WHITE);
    display.display();
    delay(40);
  }

  // Step 2: quick clear to transition.
  delay(80);
  display.clearDisplay();
  display.display();
  delay(40);

  // Step 3: show TRKEY title + version in bottom-right.
  display.clearDisplay();
  display.setTextColor(SSD1306_WHITE);
  display.setTextSize(2);
  display.setCursor(16, 18);
  display.print("TRKEY");

  display.setTextSize(1);
  int16_t x1, y1;
  uint16_t w, h;
  display.getTextBounds(FW_VERSION, 0, 0, &x1, &y1, &w, &h);
  int verX = SCREEN_WIDTH - static_cast<int>(w) - 2;
  int verY = SCREEN_HEIGHT - static_cast<int>(h) - 1;
  display.setCursor(verX, verY);
  display.print(FW_VERSION);
  display.display();

  delay(2000);
}
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
void loop() {
  uint32_t now = millis();
  processSerial();

  bool layerState = digitalRead(layerSwitchPin);
  if (lastLayerSwitchState && !layerState && !layers.empty()) {
    currentLayer = (currentLayer + 1) % layers.size();
    drawUI(currentLayer);
    delay(200);
  }
  lastLayerSwitchState = layerState;

  for (int i = 0; i < 9; i++) {
    bool released = digitalRead(keyPins[i]);
    String keyname = layers.empty() ? "" : layers[currentLayer].keys[i];

    if (!released) {
      if (now - keyDebounceStart[i] > DEBOUNCE_MS) {
        if (!repeatActive[i]) {
          sendKeyEntry(keyname, i, true);
          repeatActive[i] = true;
          repeatStart[i] = now;
          repeatLast[i] = now;
          pressedIndex = i;
          lastPressMs = now;
          drawUI(currentLayer, pressedIndex);
        } else {
          String fn;
          int target;
          bool isLayerFn = parseLayerFn(keyname, fn, target);
          if (!(isLayerFn && fn == "MO") &&
              (now - repeatStart[i] > REPEAT_DELAY_MS) &&
              (now - repeatLast[i] > REPEAT_RATE_MS)) {
            sendKeyEntry(keyname, i, true);
            repeatLast[i] = now;
            pressedIndex = i;
            lastPressMs = now;
            drawUI(currentLayer, pressedIndex);
          }
        }
      }
    } else {
      if (repeatActive[i]) {
        String fn;
        int target;
        if (parseLayerFn(keyname, fn, target) && fn == "MO") {
          sendKeyEntry(keyname, i, false);
        }
      }
      repeatActive[i] = false;
      keyDebounceStart[i] = now;
    }
  }

  if (pressedIndex >= 0 && now - lastPressMs > PRESS_DISPLAY_MS) {
    pressedIndex = -1;
    drawUI(currentLayer);
  }

  delay(10);
}

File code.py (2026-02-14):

import board
import busio
import displayio
from adafruit_displayio_ssd1306 import SSD1306
from adafruit_display_text import label
import terminalio
import time
import json
import digitalio
import usb_hid
import usb_cdc
import os

from adafruit_hid.keyboard import Keyboard
from adafruit_hid.keycode import Keycode
from adafruit_hid.consumer_control import ConsumerControl
from adafruit_hid.consumer_control_code import ConsumerControlCode
from adafruit_hid.keyboard_layout_us import KeyboardLayoutUS

# === Globals / Config ===
WIDTH, HEIGHT = 128, 64
DEBOUNCE_TIME = 0.1
PRESS_DISPLAY_TIME = 0.3
REPEAT_DELAY = 0.4   # seconds before repeat starts
REPEAT_RATE = 0.05   # seconds between repeats

last_press_time = 0
pressed_index = None

# Layers
current_layer = 0
default_layer = 0
layers = []
grid_size = 3
physical_layout = []
macros = {}  # id -> sequence (string)

# Repeat tracking
repeat_active = [False] * 9
repeat_start = [0] * 9
repeat_last = [0] * 9

# Momentary layer tracking (per key)
mo_active = [False] * 9
mo_prev_layer = [0] * 9
mo_target_for_key = [None] * 9  # if this key is MO(x), store x

# === USB CDC State ===
uart = usb_cdc.console
cdc_buffer = b""
receiving_file = False
file = None
filename = ""
companion_connected = False

# === Optional companion app state ===
SHOW_NOW_PLAYING_TIMEOUT = 10.0
show_now_playing = False
last_now_playing_update = 0.0
now_playing = {
    "title": "",
    "artist": "",
    "position": 0,
    "duration": 0,
    "source": "",
}

# === Known consumer/media codes ===
consumer_map = {
    "PLAY_PAUSE": ConsumerControlCode.PLAY_PAUSE,
    "MUTE": ConsumerControlCode.MUTE,
    "VOLUME_DECREMENT": ConsumerControlCode.VOLUME_DECREMENT,
    "VOLUME_INCREMENT": ConsumerControlCode.VOLUME_INCREMENT,
    "SCAN_NEXT_TRACK": ConsumerControlCode.SCAN_NEXT_TRACK,
    "SCAN_PREVIOUS_TRACK": ConsumerControlCode.SCAN_PREVIOUS_TRACK,
    "STOP": ConsumerControlCode.STOP,
    "RECORD": ConsumerControlCode.RECORD,
}

# === I2C Display ===
displayio.release_displays()
i2c = busio.I2C(board.GP17, board.GP16)
while not i2c.try_lock():
    pass
while 0x3C not in i2c.scan():
    print("Waiting for I2C display...")
    time.sleep(1)
i2c.unlock()

display_bus = displayio.I2CDisplay(i2c, device_address=0x3C)
display = SSD1306(display_bus, width=WIDTH, height=HEIGHT)
splash = displayio.Group()
display.root_group = splash

# === HID Devices ===
kbd = Keyboard(usb_hid.devices)
consumer_control = ConsumerControl(usb_hid.devices)
kbd_layout = KeyboardLayoutUS(kbd)

# === Buttons ===
button_pins = [
    board.GP2, board.GP3, board.GP4,
    board.GP5, board.GP6, board.GP7,
    board.GP8, board.GP9, board.GP10
]
buttons = []
button_times = []
for pin in button_pins:
    btn = digitalio.DigitalInOut(pin)
    btn.direction = digitalio.Direction.INPUT
    btn.pull = digitalio.Pull.UP
    buttons.append(btn)
    button_times.append(0)

layer_switch_btn = digitalio.DigitalInOut(board.GP15)
layer_switch_btn.direction = digitalio.Direction.INPUT
layer_switch_btn.pull = digitalio.Pull.UP
last_layer_switch_state = True

# === UI ===
key_labels = []
title_label = None
layer_group = None
now_playing_group = None
np_title_label = None
np_line_1 = None
np_line_2 = None
np_line_3 = None

app_action_fallback = {
    "APP_PLAY_PAUSE": "PLAY_PAUSE",
    "APP_NEXT": "SCAN_NEXT_TRACK",
    "APP_PREV": "SCAN_PREVIOUS_TRACK",
    "APP_MUTE": "MUTE",
    "APP_VOL_UP": "VOLUME_INCREMENT",
    "APP_VOL_DOWN": "VOLUME_DECREMENT",
}


def _fmt_seconds(value):
    try:
        total = max(0, int(value))
    except Exception:
        total = 0
    return f"{total // 60}:{total % 60:02d}"


def _truncate(text, length):
    text = str(text or "")
    if len(text) <= length:
        return text
    return text[: max(0, length - 1)] + "…"


def should_show_now_playing(now=None):
    if not show_now_playing:
        return False
    if now is None:
        now = time.monotonic()
    return (now - last_now_playing_update) <= SHOW_NOW_PLAYING_TIMEOUT


def render_layer_view(layer_index, pressed_idx=None):
    now_playing_group.hidden = True
    layer_group.hidden = False

    lyr = layers[layer_index]
    title_label.text = f"Layer: {lyr.get('name','?')} ({layer_index+1}/{len(layers)})"
    labels = lyr.get("labels", [])
    for i in range(9):
        lbl_text = safe_get(labels, i, "")
        txt = f"[{(lbl_text[:5]).center(5) if lbl_text else '     '}]"
        key_labels[i].text = txt
        key_labels[i].color = 0x00FF00 if i == pressed_idx else 0xFFFFFF


def render_now_playing_view():
    layer_group.hidden = True
    now_playing_group.hidden = False

    np_title_label.text = "Now Playing (Beta)"
    np_line_1.text = _truncate(now_playing.get("title", "No track"), 20)
    np_line_2.text = _truncate(now_playing.get("artist", "Unknown artist"), 20)

    pos = _fmt_seconds(now_playing.get("position", 0))
    dur = _fmt_seconds(now_playing.get("duration", 0))
    src = _truncate(now_playing.get("source", ""), 8)
    np_line_3.text = _truncate(f"{pos}/{dur} {src}".strip(), 20)

def init_ui():
    global key_labels, title_label
    global layer_group, now_playing_group
    global np_title_label, np_line_1, np_line_2, np_line_3
    if len(splash):
        splash.pop()

    layer_group = displayio.Group()
    title_label = label.Label(terminalio.FONT, text="", color=0xFFFFFF, x=0, y=4)
    layer_group.append(title_label)

    cell_w, cell_h, start_x, start_y = 40, 16, 4, 22
    key_labels = []
    for i in range(9):
        lbl = label.Label(
            terminalio.FONT,
            text="",
            color=0xFFFFFF,
            x=start_x + (i % 3) * cell_w,
            y=start_y + (i // 3) * cell_h
        )
        key_labels.append(lbl)
        layer_group.append(lbl)

    now_playing_group = displayio.Group()
    np_title_label = label.Label(terminalio.FONT, text="", color=0xFFFFFF, x=0, y=8)
    np_line_1 = label.Label(terminalio.FONT, text="", color=0xFFFFFF, x=0, y=24)
    np_line_2 = label.Label(terminalio.FONT, text="", color=0xFFFFFF, x=0, y=38)
    np_line_3 = label.Label(terminalio.FONT, text="", color=0x00FF00, x=0, y=52)
    now_playing_group.append(np_title_label)
    now_playing_group.append(np_line_1)
    now_playing_group.append(np_line_2)
    now_playing_group.append(np_line_3)
    now_playing_group.hidden = True

    splash.append(layer_group)
    splash.append(now_playing_group)

def safe_get(arr, idx, default=""):
    try:
        return arr[idx]
    except Exception:
        return default

def update_ui(layer_index, pressed_idx=None):
    if should_show_now_playing():
        render_now_playing_view()
    else:
        render_layer_view(layer_index, pressed_idx=pressed_idx)
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

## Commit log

2025-08-18 Update and rename v13macropad.kicad_pcb to PCB/v13macropad.kicad_pcb
    [v13macropad.kicad_pcb]
2025-08-18 Update and rename v13macropad.kicad_sch to PCB/v13macropad.kicad_sch
    [v13macropad.kicad_sch]
2025-08-18 Create CASE COMING SOON
2025-09-02 Rename macropad printed parts only.jpg to images/macropad printed parts nly.jpg
2025-09-02 Update and rename pcb.png to pcb.png
2025-11-22 Rename case/macropad bottom .stl to case/old/macropad bottom .stl
    [macropad bottom .stl]
2025-11-22 Rename macropad bottom .stl to macropad bottom .stl
    [macropad bottom .stl]
2025-11-22 Rename case/macropad mid.stl to case/oldcase/macropad mid.stl
    [macropad mid.stl]
2025-11-22 Rename case/macropad top.stl to case/oldcase/macropad top.stl
    [macropad top.stl]
2025-11-22 Create New case Placeholder
2025-11-22 Update README with new case design date and Discord info
    Updated release date for new case design and added Discord server announcement.
2025-12-12 Update case design release date in README
2025-12-24 Update README to reflect code change to Arduino C++
2026-02-14 Fallback to built-in keymap instead of OLED ERROR state
    [Trkey_macro.ino]
2026-02-14 Fix Arduino layer JSON compatibility and macro parsing
    [Trkey_macro.ino]
2026-02-14 Avoid ERROR fallback screen by loading safe default layer
    [Trkey_macro.ino]
2026-02-14 Fix HID report IDs so key presses are sent
    [Trkey_macro.ino]
2026-02-14 Accept numeric key tokens in Arduino key map
2026-02-14 Implement Arduino beta companion mode with music layer command and PC app
2026-02-14 Fix text macro typing and improve layers.json persistence path
    [Trkey_macro.ino]
2026-02-14 Fix JSON API warnings and harden LittleFS PUT persistence
    [Trkey_macro.ino]
2026-02-14 Switch to explicit HID report send with counters for diagnostics
2026-02-14 Fix keyboard report ID usage for HID typing
    [Trkey_macro.ino]
2026-02-14 Fix TinyUSB keyboard report transmission with report IDs
    [Trkey_macro.ino]
2026-02-15 Fix layer JSON reload capacity for larger configs
    [Trkey_macro.ino]
2026-02-15 Retry LittleFS mount during serial commands and reload
2026-02-15 Fix upload EOF handling, FS resilience, and input timing
    [Trkey_macro.ino]
2026-02-15 Update Trkey_macro.ino
    It load the layers.json to ram but not flash, so on reboot it lose the the mapping that was in Layers.json
    [Trkey_macro.ino]
2026-02-16 Update Trkey_macro.ino
    Replaced LittleFS with EEPROM storage
    version=2.5.4
    [Trkey_macro.ino]
2026-03-04 Update trkey_music_companion.py
    buggy as hell, dont use
    [trkey_music_companion.py]
